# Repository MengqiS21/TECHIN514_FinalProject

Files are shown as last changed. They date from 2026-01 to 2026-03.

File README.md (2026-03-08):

# Pet Activity & Proximity Tracker

A wearable sensing tag for pets and a tabletop display that visualizes daily activity and proximity-based companionship.  
The system is designed as a calm, ambient tool that supports reflection rather than real-time alerts, helping pet owners understand patterns of activity and togetherness over the course of a day. By translating sensed data into a physical gauge, the project emphasizes presence and routine over precise tracking or notifications.

## 1. Overview

### What it does
This project consists of a lightweight sensing device attached to a pet’s collar and a tabletop display device placed in the home. The system tracks the pet’s activity level and estimates proximity to the owner throughout the day, visualizing overall “bond time” using a physical gauge instead of a screen.

### General system sketch
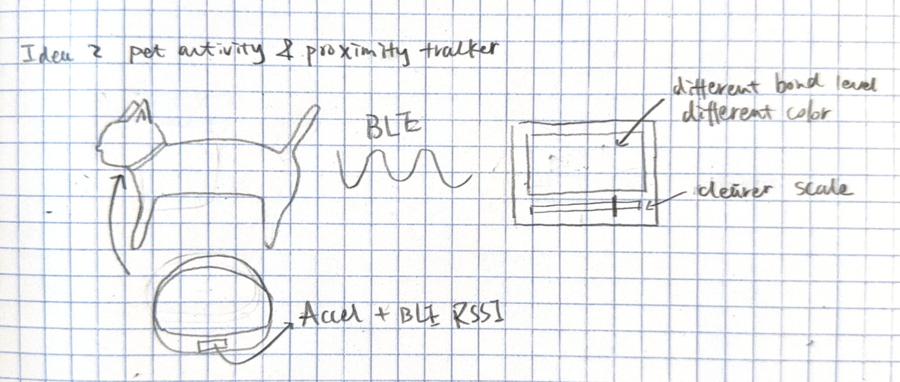
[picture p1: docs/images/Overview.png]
Overall system sketch


### Repository structure
```text
TECHIN514_FinalProject/
├─ README.md
├─ archive/
│  └─ root_pio_legacy/          # early PlatformIO prototype
├─ docs/
│  ├─ images/                   # system diagrams and renders
│  ├─ datasheets/               # component datasheets
│  └─ gantt.xlsx
├─ firmware/
│  ├─ sensor_tag/               # collar sensing tag firmware (ESP32-C3)
│  │  ├─ src/
│  │  ├─ include/
│  │  ├─ lib/
│  │  └─ test/
│  └─ display_meter/            # tabletop display firmware (ESP32-C3)
│     ├─ src/
│     ├─ include/
│     ├─ lib/
│     └─ test/
└─ hardware/
   ├─ pcb/
   │  ├─ sensor_tag/            # sensor-tag PCB project files
   │  ├─ display/               # display PCB project files
   │  ├─ legacy_pcb/            # older PCB iteration
   │  └─ PCB Production/        # Gerbers and drill files
   └─ enclosure/                # enclosure CAD/STL/STEP files
```

## 2. Sensing Device (Pet Collar Tag)

### Description
The sensing device is a lightweight tag mounted on a pet’s collar that detects motion and estimates proximity to the owner. It classifies activity levels (resting, walking, high activity) and tracks how much time the pet spends near the display device without using GPS.

### Detailed sensing device sketch
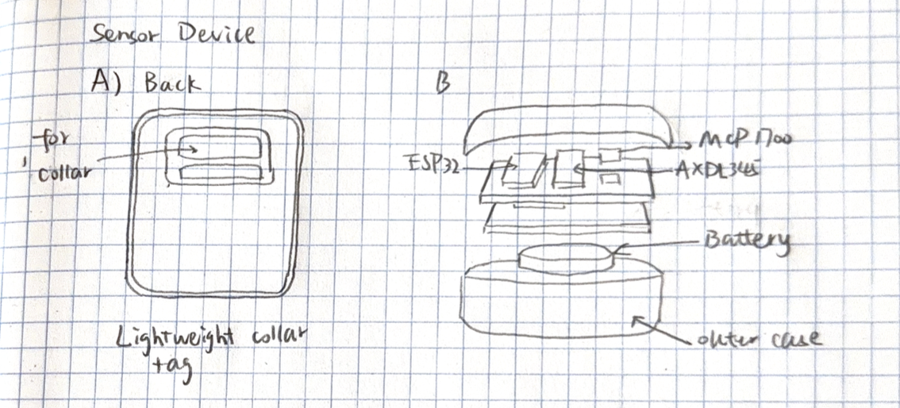
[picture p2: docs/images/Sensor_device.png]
Sensing device sketch


### How it works
- An onboard accelerometer detects motion patterns to estimate activity intensity.
- The sensor samples IMU acceleration for a short time window and computes a compact activity score.
- Summarized data is transmitted periodically to the display device via BLE.

### Signal Processing / Machine Learning (Current Implementation)
- The current system uses **lightweight signal processing**, not a trained machine learning model.
- In `firmware/sensor_tag/src/main.cpp`, the tag samples acceleration for a **1.5 s window** with a **40 ms** sample period.
- For each sample, it computes motion magnitude proxy `|ax| + |ay| + |az|`, averages over the window, and maps it linearly to a **0-100** activity score (`3g -> 100`, clamped).
- This activity score is sent to the display via BLE and mapped to motor/LED behavior.

### Accuracy Numbers (Current Status)
- A labeled dataset evaluation is not yet included in this repository.
- Therefore, formal ML metrics such as **accuracy / precision / recall / F1** are currently **N/A (not reported yet)**.

### Sensors and components (with part numbers)
- **Accelerometer:** ADXL345 (Analog Devices, 3-axis digital accelerometer)
- **Microcontroller + BLE:** ESP32-C3-MINI-1
- **Battery:** CR2032 coin cell *or* 150–300 mAh LiPo battery
- **Power management:** MCP1700 low-dropout regulator
- **Optional proximity aid:** Onboard ESP32 BLE RSSI (no extra sensor required)

## 3. Display Device (Bond Meter)

### Description
The display device is a tabletop “bond meter” that physically visualizes the pet’s daily activity and proximity time using a stepper-motor-driven gauge needle. An LED provides real-time feedback when the pet is nearby, and a button allows users to switch display modes or acknowledge the status.

### Detailed display device sketch
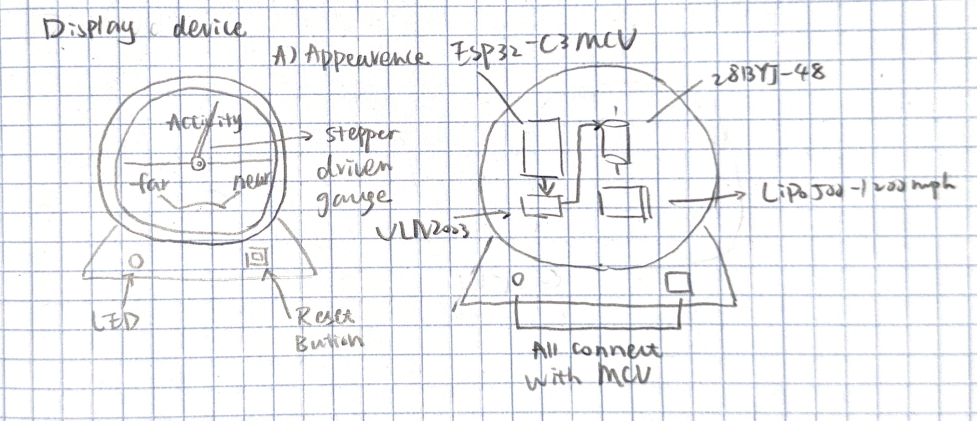
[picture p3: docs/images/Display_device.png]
Display device sketch


### How it works
- The display receives summarized activity and proximity data via BLE.
- The microcontroller maps daily totals to a gauge needle position using a stepper motor.
- The LED indicates current proximity state (e.g., pet nearby vs away).
- The button toggles display modes (activity vs proximity) or resets daily tracking.

### Components (with part numbers)
- **Microcontroller + BLE:** ESP32-C3-MINI-1
- **Stepper motor:** 28BYJ-48 stepper motor
- **Motor driver:** ULN2003 stepper driver
- **LED:** WS2812B single RGB LED *or* standard 5mm LED
- **Button:** Standard tact switch
- **Battery:** 500–1200 mAh LiPo battery

## 4. System Communication & Data Flow

### Wireless communication overview
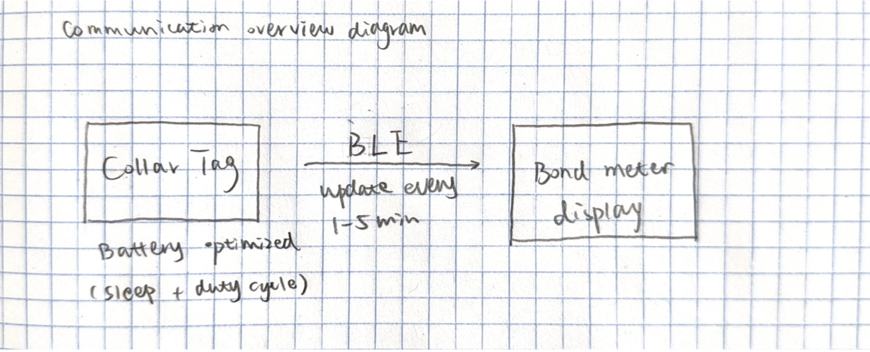
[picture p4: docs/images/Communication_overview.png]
Communication overview diagram


### Detailed system diagram
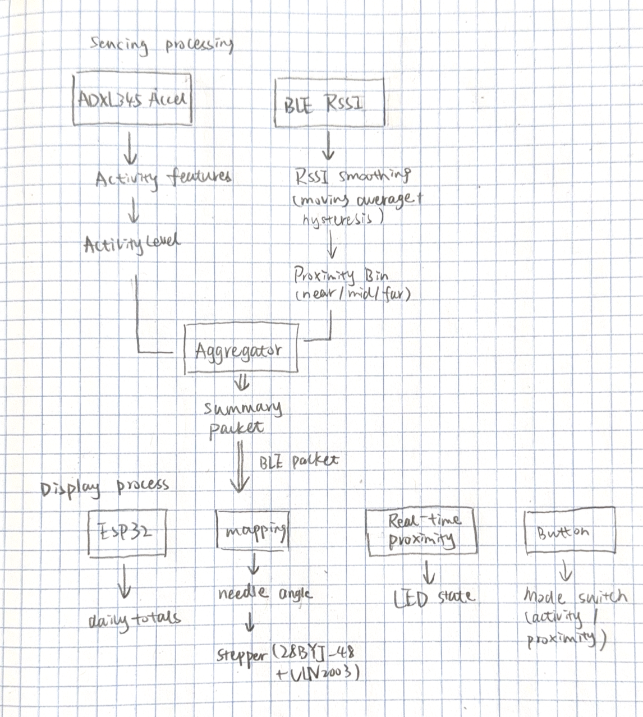
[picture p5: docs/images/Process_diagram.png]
Detailed data flow diagram


## Notes on Power and Feasibility
Both devices are battery-powered and optimized for low-duty-cycle operation. The sensing device minimizes power usage through aggressive sleep scheduling, while the display device uses short stepper motor movements and infrequent updates to maintain reasonable battery life.

### Schematic and PCB Design
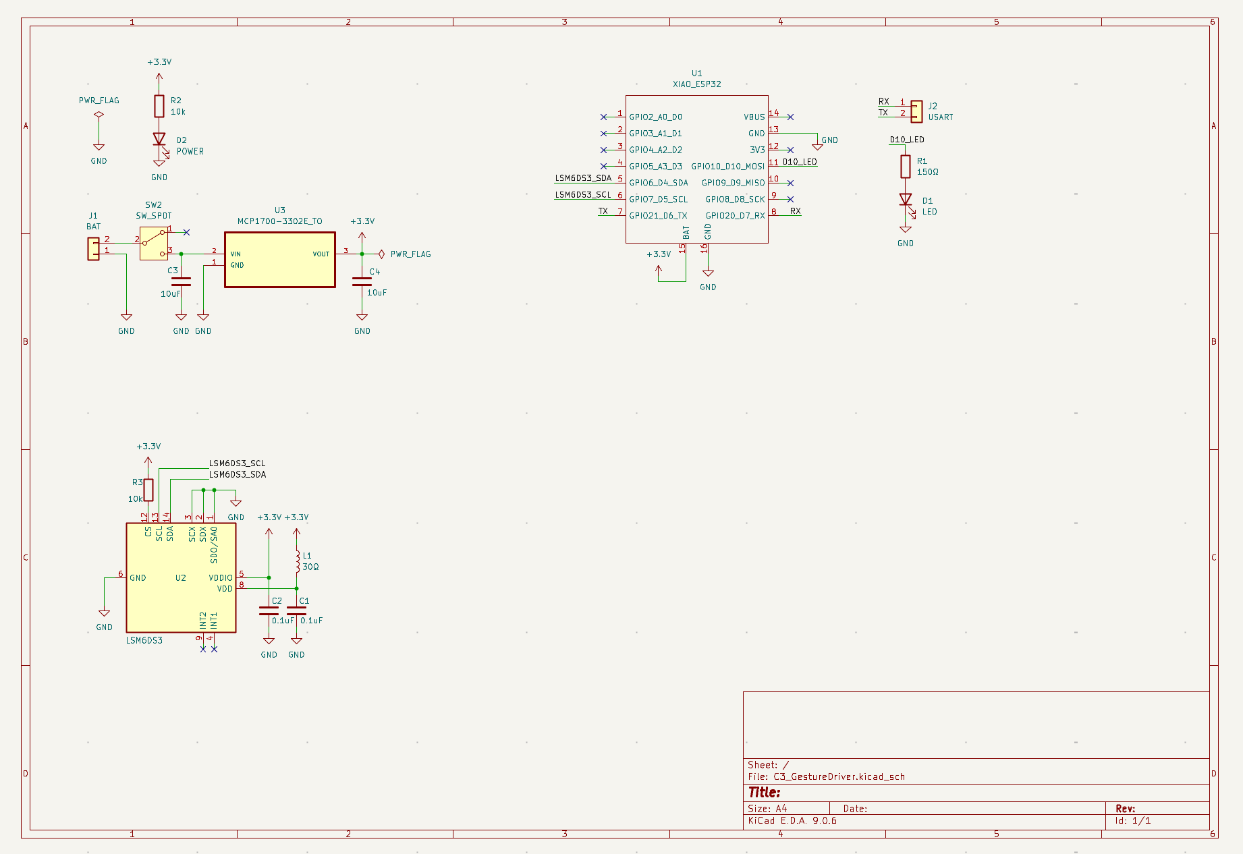
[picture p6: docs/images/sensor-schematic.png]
Detailed Sensor Schematic

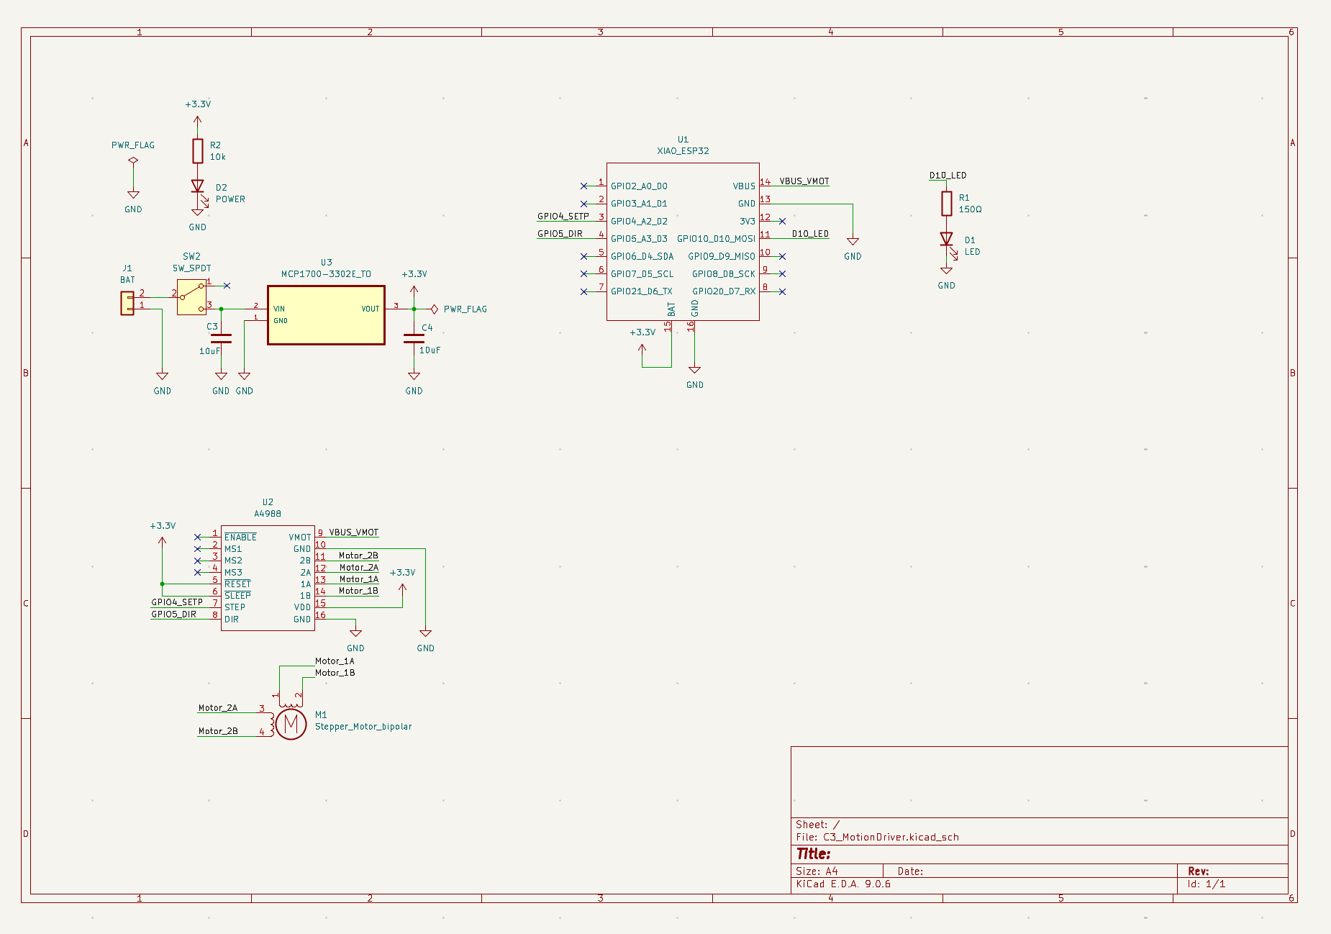
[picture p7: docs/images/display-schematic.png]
Detailed Display Schematic

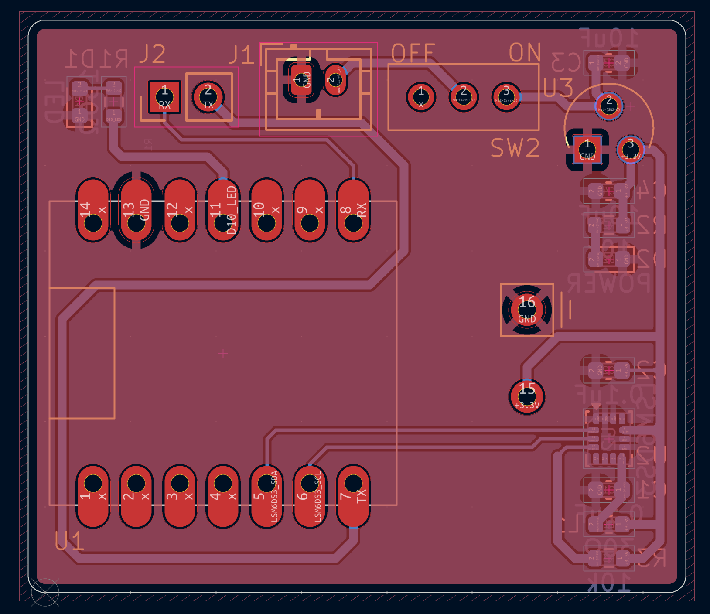
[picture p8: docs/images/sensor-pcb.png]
Detailed PCB


### PCB Production
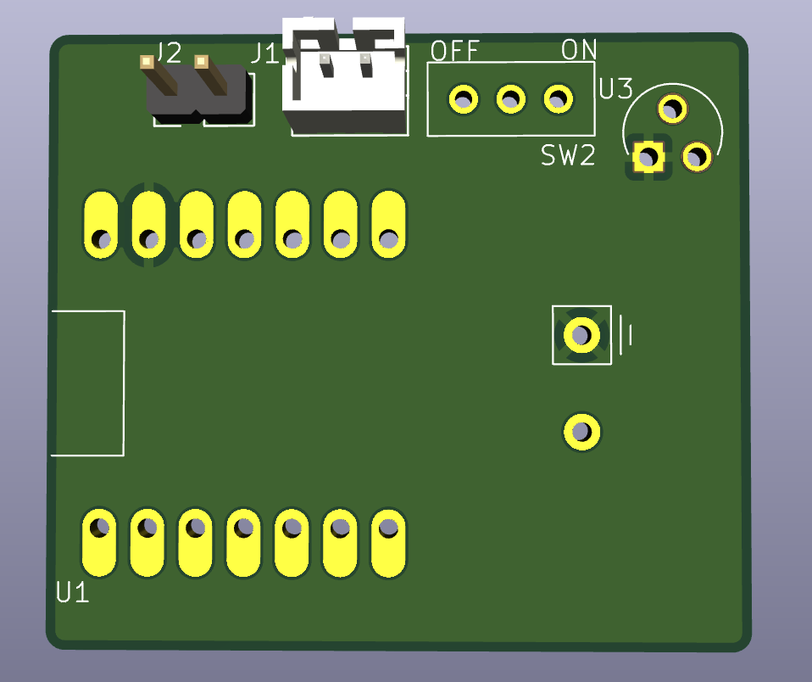
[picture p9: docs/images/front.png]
Detailed 3D View Front PCB

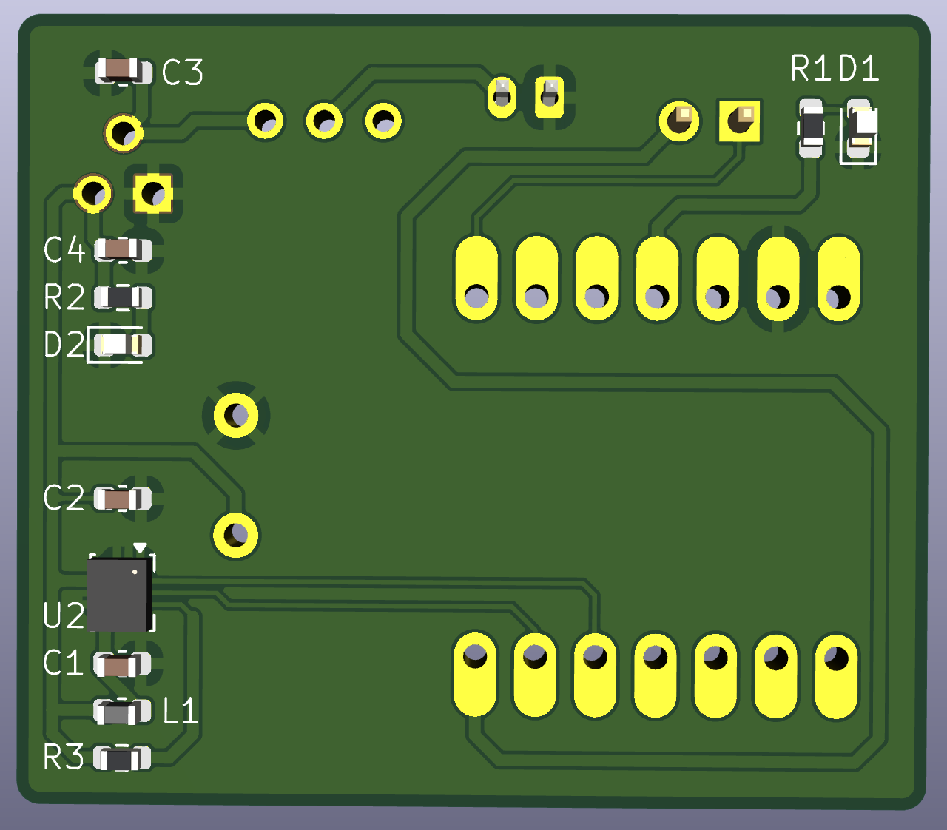
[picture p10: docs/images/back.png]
Detailed 3D View Back PCB


### Battery Life Estimation
https://docs.google.com/spreadsheets/d/1o1SAS0YDETgxqNn3ZR0W69rIJqL8Xmiv9CGHoeJ4H2A/edit?usp=sharing

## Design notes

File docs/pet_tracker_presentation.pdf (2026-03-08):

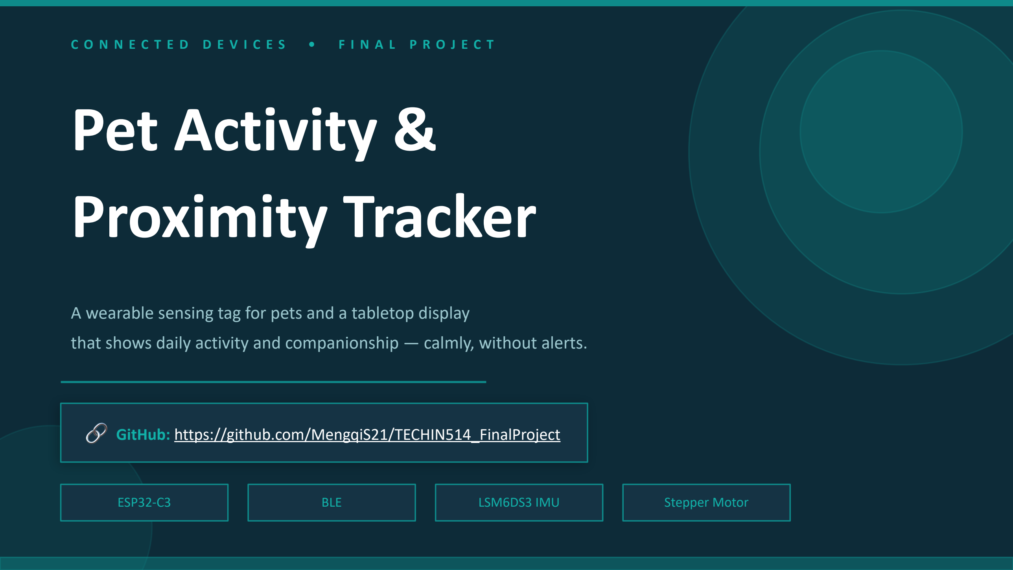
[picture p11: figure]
CONNECTED DEVICES; FINAL PROJECT; Pet Activity & Proximity Tracker; 🔗 GitHub: https://github.com/MengqiS21/TECHIN514_FinalProject; ESP32-C3; BLE; LSM6DS3 IMU; Stepper Motor

### A wearable sensing tag for pets and a tabletop display

that shows daily activity and companionship — calmly, without alerts.

# The Problem

### 😔 You don't know what your pet does all day

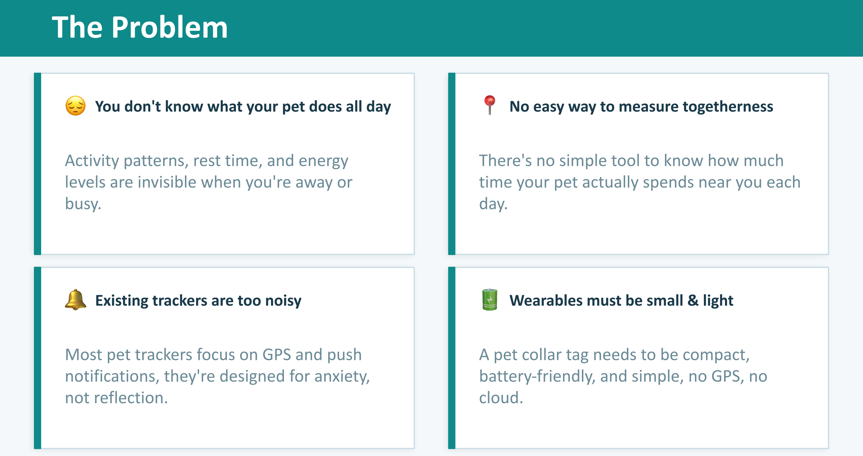
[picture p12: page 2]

## Activity patterns, rest time, and energy levels are invisible when you're away or

busy.

### 📍 No easy way to measure togetherness

## There's no simple tool to know how much time your pet actually spends near you each

day.

### 🔔 Existing trackers are too noisy

## Most pet trackers focus on GPS and push

notifications, they're designed for anxiety, not reflection.

### 🔋 Wearables must be small & light

A pet collar tag needs to be compact,

## battery-friendly, and simple, no GPS, no

cloud.

# Proposed Solution

## 🐾 Collar Sensing Tag

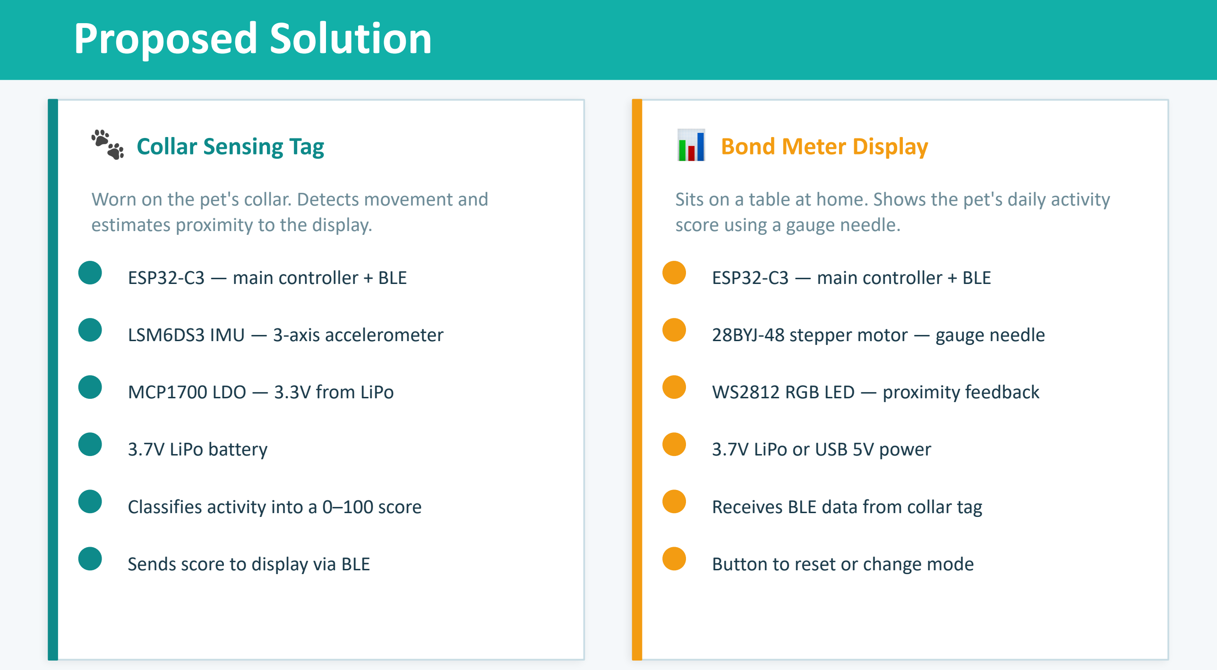
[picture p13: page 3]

Worn on the pet's collar. Detects movement and estimates proximity to the display.

ESP32-C3 — main controller + BLE

LSM6DS3 IMU — 3-axis accelerometer

MCP1700 LDO — 3.3V from LiPo

3.7V LiPo battery

Classifies activity into a 0–100 score

Sends score to display via BLE

## 📊 Bond Meter Display

Sits on a table at home. Shows the pet's daily activity score using a gauge needle.

ESP32-C3 — main controller + BLE

28BYJ-48 stepper motor — gauge needle

WS2812 RGB LED — proximity feedback

3.7V LiPo or USB 5V power

Receives BLE data from collar tag

Button to reset or change mode

# System Architecture

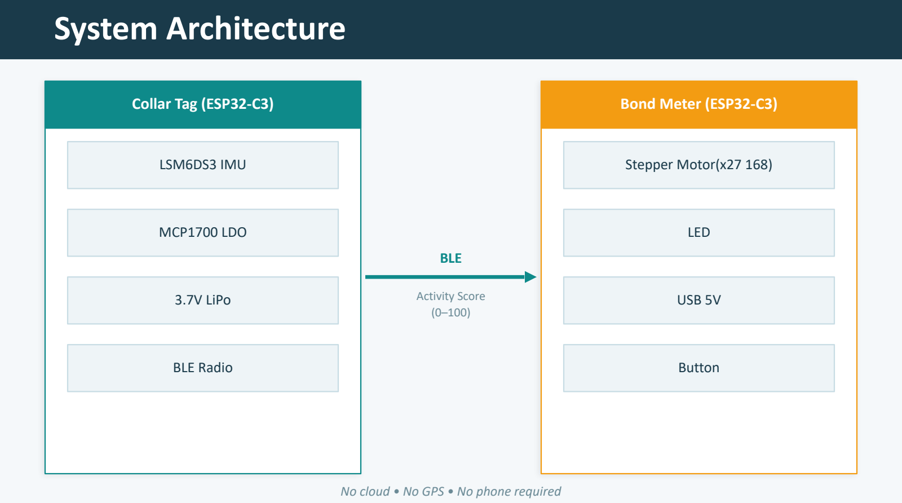
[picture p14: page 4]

### Collar Tag (ESP32-C3)

LSM6DS3 IMU

MCP1700 LDO

3.7V LiPo

BLE Radio

BLE

Activity Score
(0–100)

### Bond Meter (ESP32-C3)

Stepper Motor(x27 168)

LED

USB 5V

Button

No cloud • No GPS • No phone required

# Critical Components & PCB

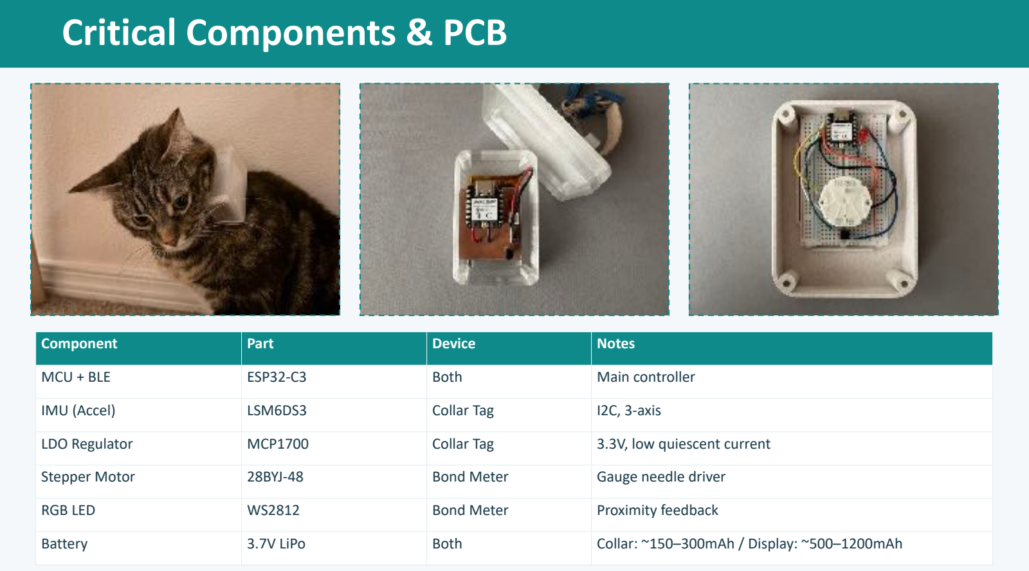
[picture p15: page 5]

Component | Part | Device | Notes
MCU + BLE | ESP32-C3 | Both | Main controller
IMU (Accel) | LSM6DS3 | Collar Tag | I2C, 3-axis
LDO Regulator | MCP1700 | Collar Tag | 3.3V, low quiescent current
Stepper Motor | 28BYJ-48 | Bond Meter | Gauge needle driver
RGB LED | WS2812 | Bond Meter | Proximity feedback
Battery | 3.7V LiPo | Both | Collar: ~150–300mAh / Display: ~500–1200mAh

# Signal Processing

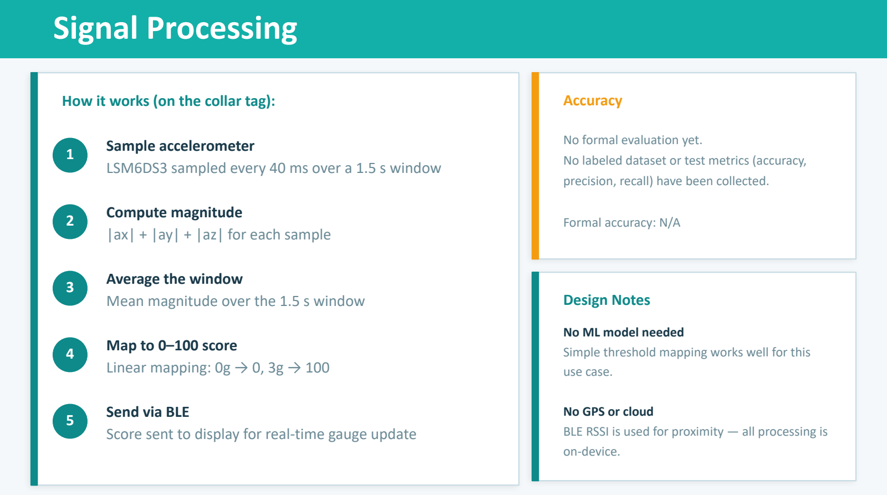
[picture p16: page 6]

### How it works (on the collar tag):

### 1 Sample accelerometer LSM6DS3 sampled every 40 ms over a 1.5 s window

### 2 Compute magnitude |ax| + |ay| + |az| for each sample

### 3 Average the window Mean magnitude over the 1.5 s window

### 4 Map to 0–100 score Linear mapping: 0g → 0, 3g → 100

### 5 Send via BLE Score sent to display for real-time gauge update

### Accuracy

No formal evaluation yet.
No labeled dataset or test metrics (accuracy, precision, recall) have been collected.

Formal accuracy: N/A

### Design Notes

No ML model needed
Simple threshold mapping works well for this use case.

No GPS or cloud
BLE RSSI is used for proximity — all processing is on-device.

# Battery Considerations

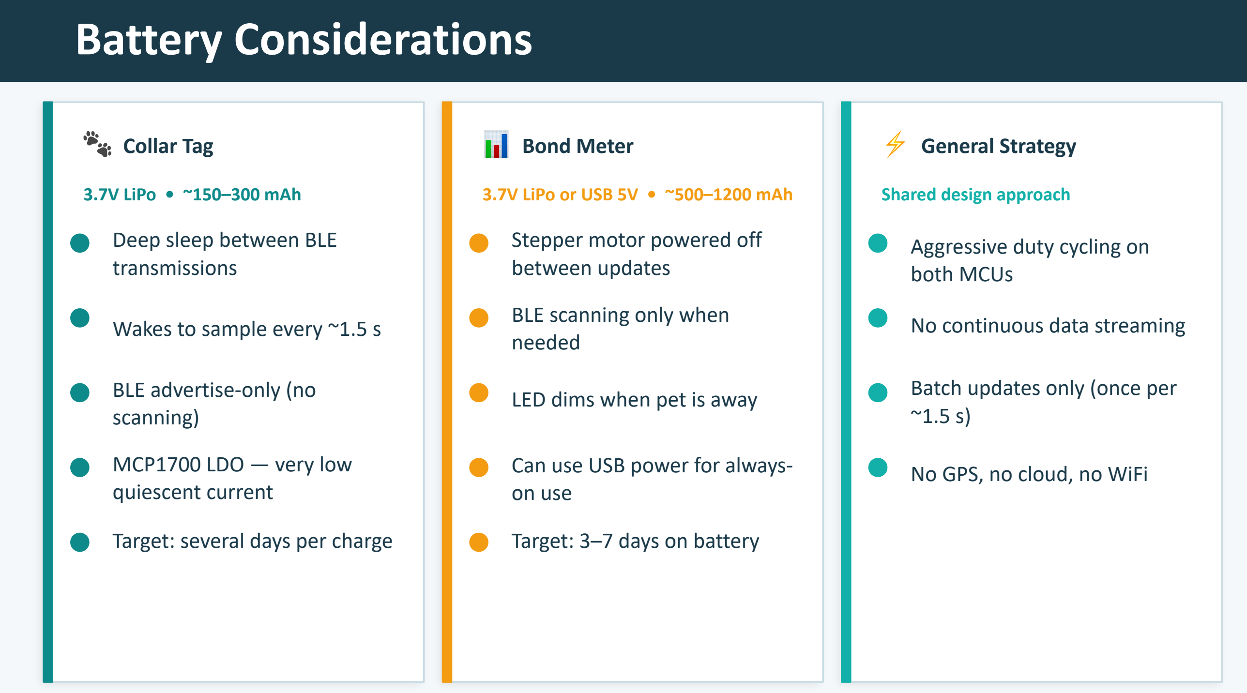
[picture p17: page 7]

### 🐾 Collar Tag

3.7V LiPo • ~150–300 mAh

### Deep sleep between BLE transmissions

### Wakes to sample every ~1.5 s

### BLE advertise-only (no scanning)

### MCP1700 LDO — very low quiescent current

### Target: several days per charge

### 📊 Bond Meter

3.7V LiPo or USB 5V • ~500–1200 mAh

### Stepper motor powered off between updates

### BLE scanning only when needed

### LED dims when pet is away

### Can use USB power for always-on use

### Target: 3–7 days on battery

### ⚡ General Strategy

Shared design approach

### Aggressive duty cycling on both MCUs

### No continuous data streaming

### Batch updates only (once per

~1.5 s)

### No GPS, no cloud, no WiFi

# Budget Summary

Component | Part | Qty | Unit Cost | Total
MCU (ESP32-C3) | Seeed Studio ESP32-C3 XIAO dev module | 2 | ~$10.00 | ~$20.00
IMU | LSM6DS3 module | 1 | ~$7.00 | ~$7.00
LDO Regulator | MCP1700 | 1 | ~$0.95 | ~$0.95
Stepper Motor | X27 168 | 1 | ~$8.00 | ~$8.00
RGB LED | WS2812 | 1 | ~$0.10 | ~$0.10
I2C Pull-up Resistors | 4.7kΩ or 10kΩ ×2 | 1 set | ~$0.10 | ~$0.10
220Ω Resistor | Standard | 1 | <$0.10 | <$0.10
Batteries | LiPo ×2 + connectors | — | ~$8.99 | ~$17.98
PCB Fabrication | JLCPCB / PCBWay (×2 boards) | — | ~$10.00 | ~$10.00
Misc (switch, connectors, enclosure) | — | — | — | ~$8.00
TOTAL ESTIMATED | | | | ~$72.23

* All costs estimated. Final BOM depends on supplier and order quantity.

# Future Work

## 🤖 Collect labeled data & evaluate accuracy

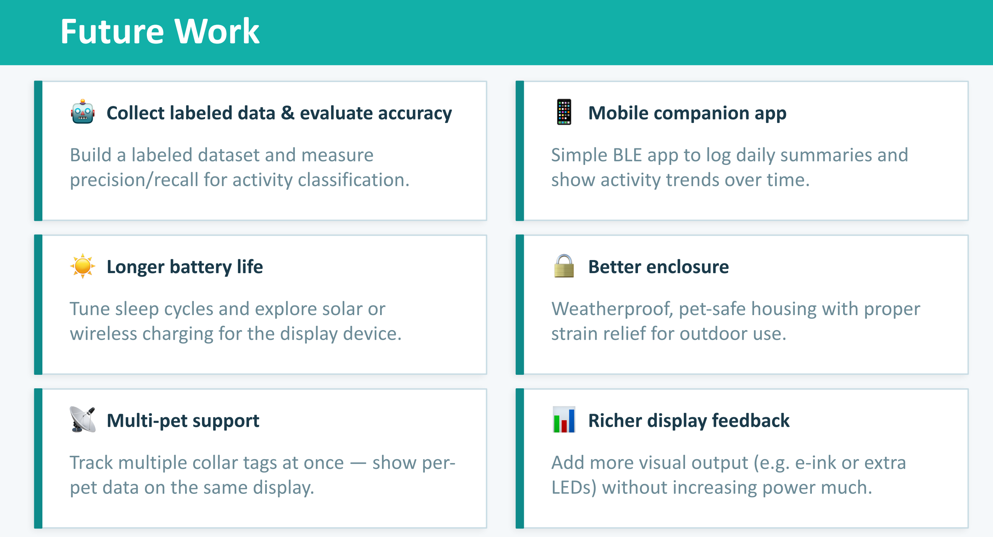
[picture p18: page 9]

## Build a labeled dataset and measure

precision/recall for activity classification.

## 📱 Mobile companion app

## Simple BLE app to log daily summaries and

show activity trends over time.

## ☀ Longer battery life

## Tune sleep cycles and explore solar or

wireless charging for the display device.

## 🔒 Better enclosure

## Weatherproof, pet-safe housing with proper

strain relief for outdoor use.

## 📡 Multi-pet support

## Track multiple collar tags at once — show per-

pet data on the same display.

## 📊 Richer display feedback

## Add more visual output (e.g. e-ink or extra

LEDs) without increasing power much.

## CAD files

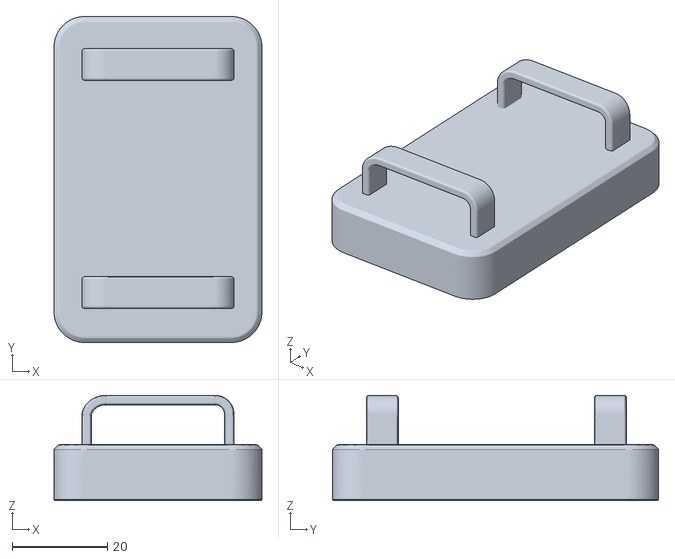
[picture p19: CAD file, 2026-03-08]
hardware/enclosure/sensor-enclosure-top.stl
43.7 x 68.5 x 22.1

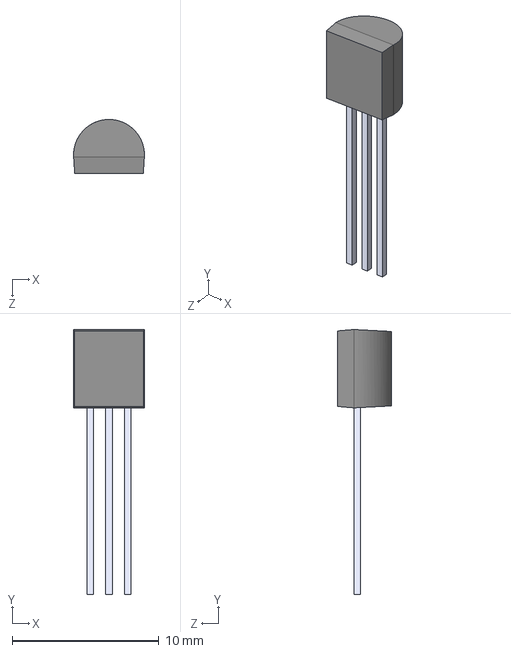
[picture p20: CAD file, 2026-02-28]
hardware/pcb/sensor_tag/MCP1700-3302E_TO/MCP1700-3302E_TO.step
4.82 x 18.0 x 3.68 mm

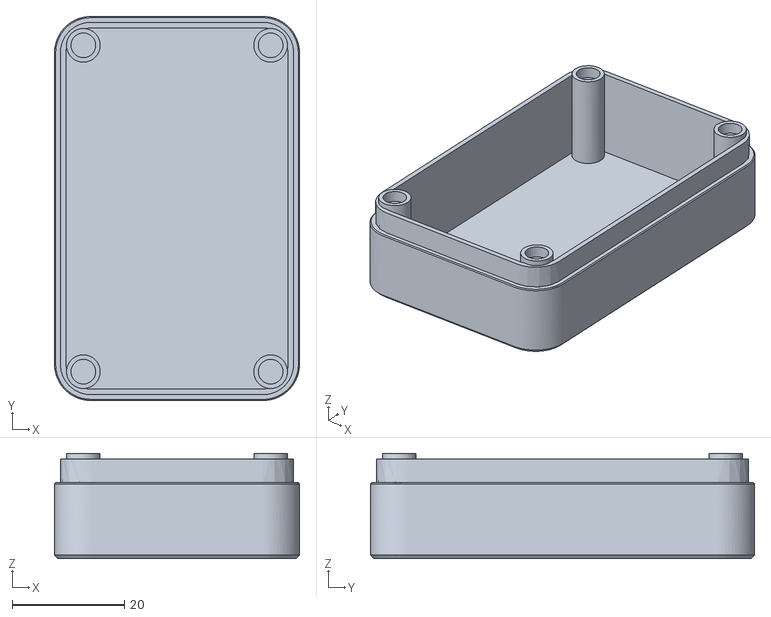
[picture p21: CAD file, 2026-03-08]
hardware/enclosure/sensor-enclosure-base.stl
43.7 x 68.5 x 18.8

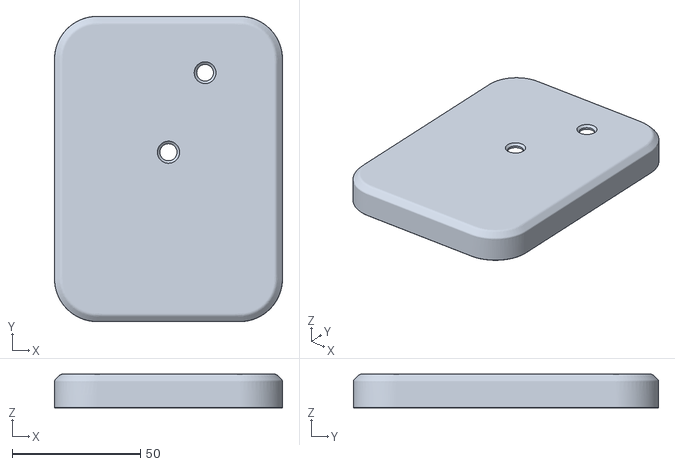
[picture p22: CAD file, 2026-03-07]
hardware/enclosure/display enclosure top.stl
88.8 x 118.9 x 13.2

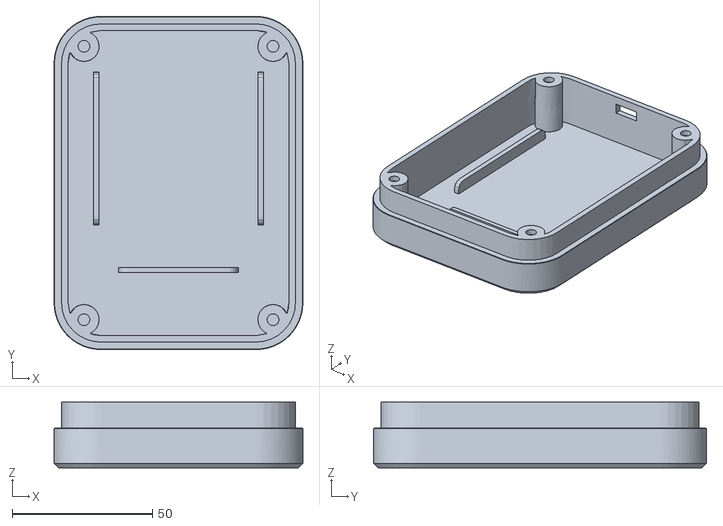
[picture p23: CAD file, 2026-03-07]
hardware/enclosure/display enclosure base.stl
88.8 x 118.9 x 23.5

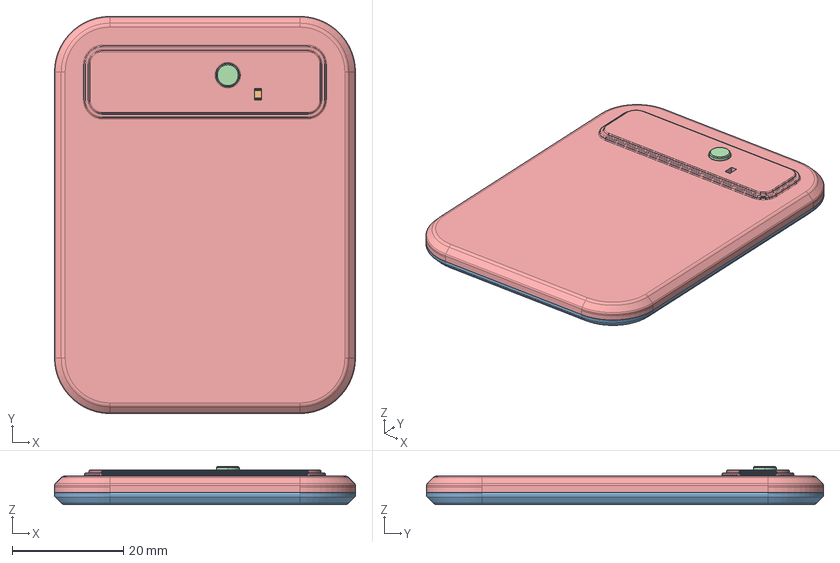
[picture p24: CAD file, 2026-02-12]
hardware/enclosure/PCB enclosure.stp
54.1 x 71.4 x 6.90 mm

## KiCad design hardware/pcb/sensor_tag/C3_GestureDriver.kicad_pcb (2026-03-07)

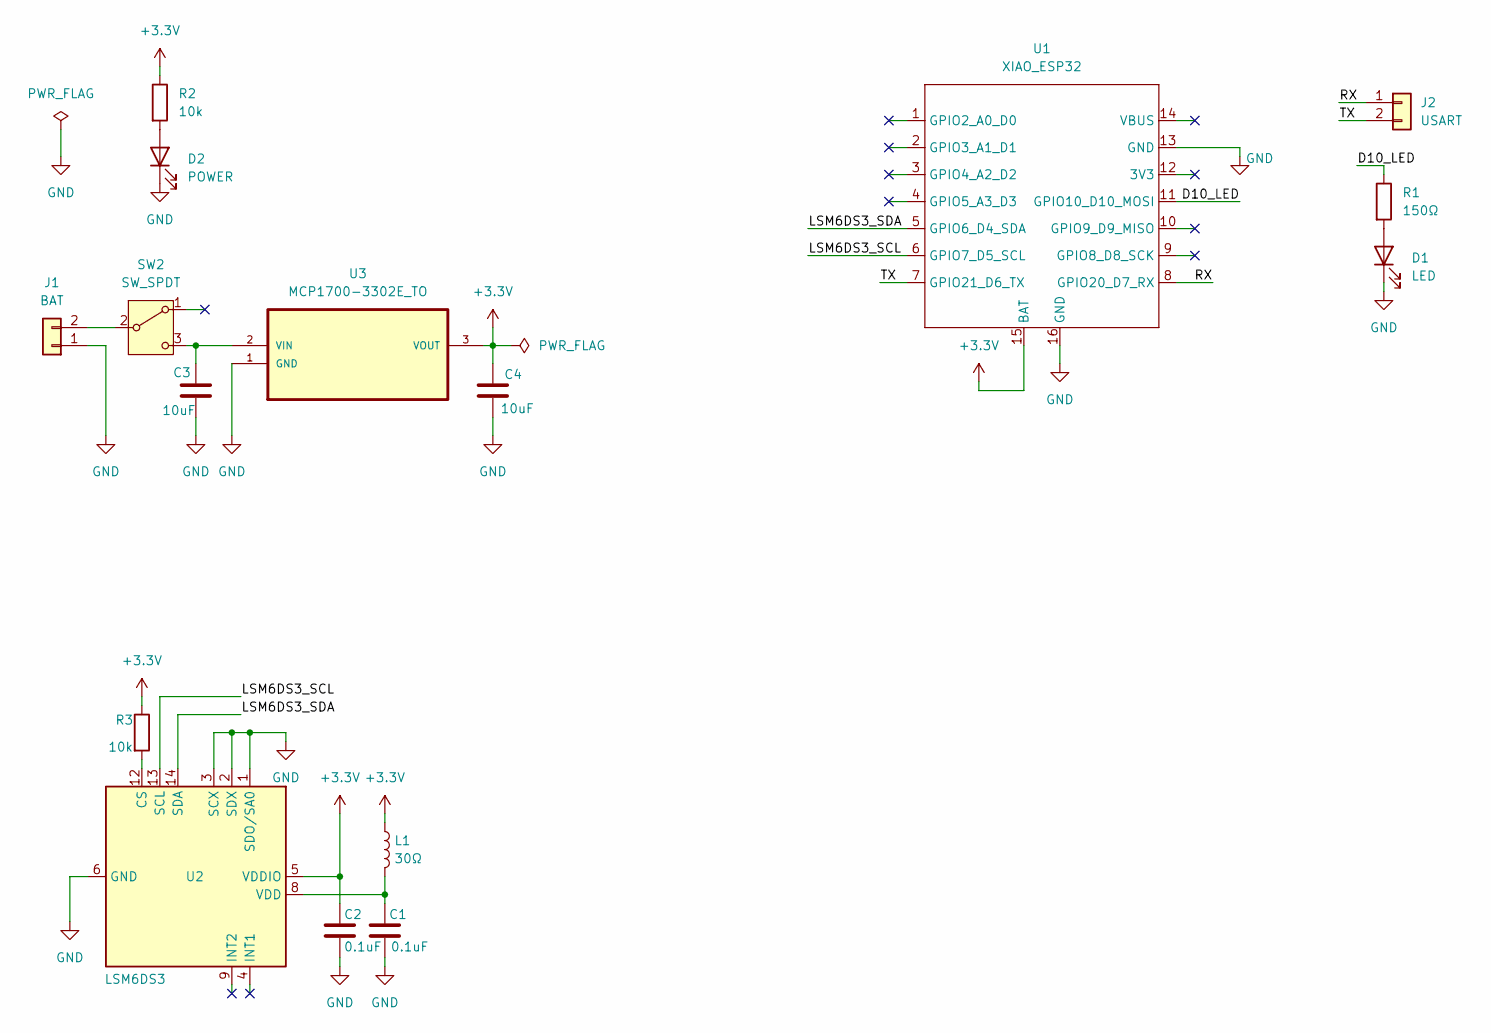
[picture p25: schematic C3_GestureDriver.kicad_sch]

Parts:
C1, C2: 0.1uF; C_0603_1608Metric
C3, C4: 10uF; C_0603_1608Metric
D1: LED; LED_0603_1608Metric
D2: POWER; LED_0603_1608Metric
J1: BAT; JST_PH_B2B-PH-K_1x02_P2.00mm_Vertical
J2: USART; PinHeader_1x02_P2.54mm_Vertical
L1: 30Ω; L_0603_1608Metric
R1: 150Ω; R_0603_1608Metric
R2, R3: 10k; R_0603_1608Metric
SW2: SW_SPDT; SS-12D00-Gx
U1: XIAO_ESP32
U2: LSM6DS3; LGA-14_3x2.5mm_P0.5mm_LayoutBorder3x4y
U3: MCP1700-3302E_TO; TO127P254X495-3; MPN MCP1700-3302E/TO

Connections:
+3.3V: C2.1, C4.1, L1.1, R2.1, R3.1, U1.15 (BAT), U2.5 (VDDIO), U3.3 (VOUT)
/D10_LED: R1.1, U1.11 (GPIO10_D10_MOSI)
/LSM6DS3_SCL: U1.6 (GPIO7_D5_SCL), U2.13 (SCL)
/LSM6DS3_SDA: U1.5 (GPIO6_D4_SDA), U2.14 (SDA)
/RX: J2.1, U1.8 (GPIO20_D7_RX)
/TX: J2.2, U1.7 (GPIO21_D6_TX)
GND: C1.2, C2.2, C3.2, C4.2, D1.1 (K), D2.1 (K), J1.1, U1.13 (GND), U1.16 (GND), U2.1 (SDO/SA0), U2.2 (SDX), U2.3 (SCX), U2.6 (GND), U2.7 (GND), U3.1 (GND)
unnamed: D1.2 (A), R1.2
unnamed: D2.2 (A), R2.2
unnamed: J1.2, SW2.2 (B)
unnamed: C3.1, SW2.3 (C), U3.2 (VIN)
unnamed: R3.2, U2.12 (CS)
unnamed: C1.1, L1.2, U2.8 (VDD)

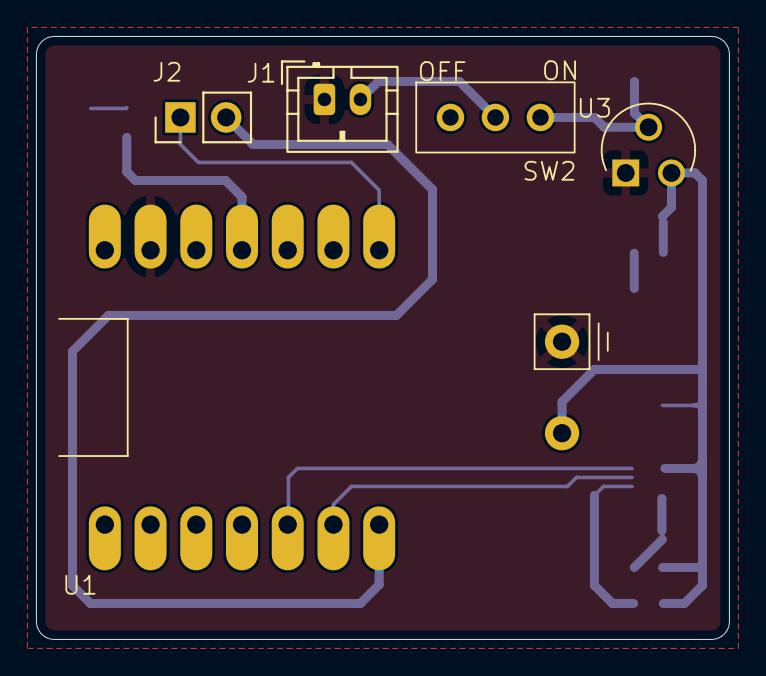
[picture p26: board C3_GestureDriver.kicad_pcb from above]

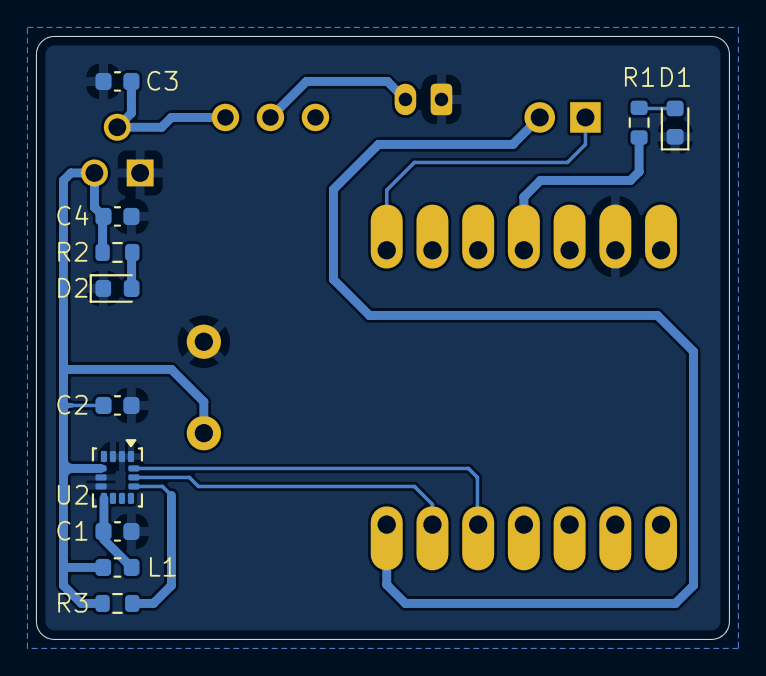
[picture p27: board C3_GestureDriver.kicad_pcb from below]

Board: 2 copper layers, 38.5 x 33.5 mm, 16 parts (11 on the bottom side), 13 nets.

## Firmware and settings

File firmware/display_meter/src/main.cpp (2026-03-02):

#include <Arduino.h>
#include <BLEDevice.h>
#include <cstring>

#include "ble_protocol.h"
#include "config.h"
#include "led_status.h"
#include "motor_gauge.h"
#include "pins.h"
#include "power_stages.h"

enum class DisplayState {
  BOOT,
  BLE_SCAN_CONNECT,
  WAIT_FOR_DATA,
  UPDATE_DISPLAY,
  IDLE,
};

namespace {

class DisplayClientCallbacks : public BLEClientCallbacks {
 public:
  void onConnect(BLEClient* /*client*/) override {}

  void onDisconnect(BLEClient* /*client*/) override {
    Serial.println("BLE disconnected.");
    connected_ = false;
  }

  bool connected() const { return connected_; }
  void setConnected(bool value) { connected_ = value; }

 private:
  bool connected_ = false;
};

DisplayState g_state = DisplayState::BOOT;
DisplayClientCallbacks g_client_callbacks;
BLEClient* g_client = nullptr;
BLERemoteCharacteristic* g_remote_char = nullptr;

ActivityPayload g_last_payload{};
volatile bool g_payload_ready = false;
uint32_t g_wait_start_ms = 0;

bool g_motor_ready = false;
bool g_ble_initialized = false;

void notifyCallback(BLERemoteCharacteristic* /*remote*/, uint8_t* data, size_t len, bool /*isNotify*/) {
  if (len < sizeof(ActivityPayload)) {
    return;
  }
  memcpy(&g_last_payload, data, sizeof(ActivityPayload));
  g_payload_ready = true;
}

bool validatePins() {
  bool ok = true;
  if (PIN_MOTOR_IN1 < 0) {
    Serial.println("ERROR: PIN_MOTOR_IN1 not set. Edit include/pins.h");
    ok = false;
  }
  if (PIN_MOTOR_IN2 < 0) {
    Serial.println("ERROR: PIN_MOTOR_IN2 not set. Edit include/pins.h");
    ok = false;
  }
  if (PIN_MOTOR_IN3 < 0) {
    Serial.println("ERROR: PIN_MOTOR_IN3 not set. Edit include/pins.h");
    ok = false;
  }
  if (PIN_MOTOR_IN4 < 0) {
    Serial.println("ERROR: PIN_MOTOR_IN4 not set. Edit include/pins.h");
    ok = false;
  }
  return ok;
}

bool ensureBleInit() {
  if (g_ble_initialized) {
    return true;
  }
  BLEDevice::init(kBleDeviceName);
  g_ble_initialized = true;
  return true;
}

bool connectToSensor() {
  if (!ensureBleInit()) {
    return false;
  }

  BLEScan* scan = BLEDevice::getScan();
  scan->setActiveScan(true);
  BLEScanResults results = scan->start(kBleScanSeconds, false);

  BLEAdvertisedDevice* target = nullptr;
  for (int i = 0; i < results.getCount(); ++i) {
    BLEAdvertisedDevice device = results.getDevice(i);
    if (device.haveServiceUUID() && device.isAdvertisingService(BLEUUID(BLE_SERVICE_UUID))) {
      target = new BLEAdvertisedDevice(device);
      break;
    }
  }

  scan->clearResults();

  if (target == nullptr) {
    Serial.println("BLE scan: target service not found.");
    return false;
  }

  if (g_client == nullptr) {
    g_client = BLEDevice::createClient();
    g_client->setClientCallbacks(&g_client_callbacks);
  }

  if (!g_client->connect(target)) {
    Serial.println("BLE connect failed.");
    delete target;
    return false;
  }
  delete target;
  delay(500);  // Allow GATT attribute discovery to complete

  BLERemoteService* service = g_client->getService(BLEUUID(BLE_SERVICE_UUID));
  if (service == nullptr) {
    Serial.println("BLE service missing on peer.");
    g_client->disconnect();
    return false;
  }

  g_remote_char = service->getCharacteristic(BLEUUID(BLE_CHAR_UUID));
  if (g_remote_char == nullptr) {
    Serial.println("BLE characteristic missing on peer.");
    g_client->disconnect();
    return false;
  }

  if (!g_remote_char->canNotify()) {
    Serial.println("BLE characteristic does not support notify.");
    g_client->disconnect();
    return false;
  }

  BLERemoteDescriptor* cccd =
      g_remote_char->getDescriptor(BLEUUID((uint16_t)0x2902));
  if (cccd == nullptr) {
    Serial.println("BLE CCCD descriptor not found on peer.");
    g_client->disconnect();
    return false;
  }

  if (!g_remote_char->registerForNotify(notifyCallback)) {
    Serial.println("BLE notify subscription failed.");
    g_client->disconnect();
    return false;
  }

  g_client_callbacks.setConnected(true);
  g_wait_start_ms = millis();
  return true;
}

bool isBleConnected() {
  if (g_client == nullptr) {
    return false;
  }
  return g_client->isConnected() && g_client_callbacks.connected();
}

void updateDisplayFromPayload() {
  const uint16_t activity = (g_last_payload.activity > 100) ? 100 : g_last_payload.activity;

  Serial.print("RX seq=");
  Serial.print(g_last_payload.seq);
  Serial.print(" activity=");
  Serial.print(activity);
  Serial.print(" battery_mv=");
  Serial.println(g_last_payload.battery_mv);

  if (g_motor_ready) {
    motor_gauge::setTargetFromActivity(activity);
  } else {
    Serial.println("Motor pins not configured; display update is print-only.");
  }
  led_status::setFromActivity(activity);
}

}  // namespace

void setup() {
  Serial.begin(115200);
  delay(300);
}

void loop() {
  switch (g_state) {
    case DisplayState::BOOT:
      validatePins();
      g_motor_ready = motor_gauge::init();
      led_status::init();
      g_state = DisplayState::BLE_SCAN_CONNECT;
      break;

    case DisplayState::BLE_SCAN_CONNECT:
      LOG_STAGE("BLE_SCAN");
      if (connectToSensor()) {
        LOG_STAGE("BLE_CONNECTED");
        g_state = DisplayState::WAIT_FOR_DATA;
      } else {
        delay(400);
      }
      break;

    case DisplayState::WAIT_FOR_DATA:
      if (!isBleConnected()) {
        g_state = DisplayState::BLE_SCAN_CONNECT;
        break;
      }

      if (g_payload_ready) {
        g_state = DisplayState::UPDATE_DISPLAY;
        break;
      }

      if (millis() - g_wait_start_ms > kDataWaitTimeoutMs) {
        g_state = DisplayState::IDLE;
      }
      delay(20);
      break;

    case DisplayState::UPDATE_DISPLAY:
      LOG_STAGE("DISPLAY_UPDATE");
      updateDisplayFromPayload();
      g_payload_ready = false;
      g_wait_start_ms = millis();
      g_state = DisplayState::WAIT_FOR_DATA;
      break;

    case DisplayState::IDLE:
      LOG_STAGE("IDLE");
      delay(kIdleDelayMs);
      if (!isBleConnected()) {
        g_state = DisplayState::BLE_SCAN_CONNECT;
      } else {
        g_wait_start_ms = millis();
        g_state = DisplayState::WAIT_FOR_DATA;
      }
      break;
  }
}

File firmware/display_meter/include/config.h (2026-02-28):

#ifndef DISPLAY_CONFIG_H
#define DISPLAY_CONFIG_H

#include <stdint.h>

static constexpr const char* kBleDeviceName = "TECHIN514_DISPLAY";
static constexpr const char* kBleServiceUuid = "6f7f0001-8f3b-4c3a-a39a-3f8ec4dca101";
static constexpr const char* kBleCharUuid = "6f7f0002-8f3b-4c3a-a39a-3f8ec4dca101";

static constexpr uint32_t kBleScanSeconds = 4;
static constexpr uint32_t kDataWaitTimeoutMs = 8000;
static constexpr uint32_t kIdleDelayMs = 300;

static constexpr int kGaugeMaxSteps = 600;
static constexpr uint32_t kMotorStepDelayUs = 1200;

#endif

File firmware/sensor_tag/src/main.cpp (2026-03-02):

#include <Arduino.h>
#include <BLEDevice.h>
#include <esp_sleep.h>
#include <math.h>

#include "activity_algo.h"
#include "ble_protocol.h"
#include "config.h"
#include "imu_lsm6ds3.h"
#include "pins.h"
#include "power_stages.h"

enum class SensorState {
  BOOT,
  IMU_INIT,
  SENSE_IMU,
  PROCESS,
  BLE_TX,
  RADIO_OFF,
  DEEP_SLEEP,
};

namespace {

class SensorServerCallbacks : public BLEServerCallbacks {
 public:
  void onConnect(BLEServer* /*server*/) override { connected_ = true; }
  void onDisconnect(BLEServer* server) override {
    connected_ = false;
    server->startAdvertising();
  }

  bool isConnected() const { return connected_; }

 private:
  bool connected_ = false;
};

SensorState g_state = SensorState::BOOT;
imu::Lsm6ds3 g_imu;
bool g_has_i2c_pins = false;
bool g_imu_ready = false;
uint32_t g_seq = 0;
uint16_t g_activity = 0;
uint16_t g_battery_mv = 0;

float g_sum_abs_accel = 0.0f;
uint32_t g_sample_count = 0;

bool validateRequiredPins() {
  bool ok = true;
  if (PIN_I2C_SDA < 0) {
    Serial.println("ERROR: PIN_I2C_SDA not set. Edit include/pins.h");
    ok = false;
  }
  if (PIN_I2C_SCL < 0) {
    Serial.println("ERROR: PIN_I2C_SCL not set. Edit include/pins.h");
    ok = false;
  }
  return ok;
}

uint16_t readBatteryMv() {
  if (PIN_BATTERY_ADC < 0) {
    return 0;
  }
  const int raw = analogRead(PIN_BATTERY_ADC);
  // Minimal placeholder conversion for 12-bit ADC @ 3.3V.
  const uint32_t mv = static_cast<uint32_t>(raw) * 3300UL / 4095UL;
  return static_cast<uint16_t>(mv);
}

void sampleImuWindow() {
  LOG_STAGE("IMU_SAMPLING_START");
  g_sum_abs_accel = 0.0f;
  g_sample_count = 0;

  if (!g_imu_ready) {
    Serial.println("IMU not ready; skipping sampling.");
    return;
  }

  const uint32_t start_ms = millis();
  while (millis() - start_ms < kImuSampleWindowMs) {
    imu::Sample s = {0.0f, 0.0f, 0.0f};
    if (g_imu.readAccel(s)) {
      g_sum_abs_accel += fabsf(s.ax_g) + fabsf(s.ay_g) + fabsf(s.az_g);
      ++g_sample_count;
    }
    delay(kImuSamplePeriodMs);
  }

  Serial.print("IMU samples: ");
  Serial.println(g_sample_count);
}

void sendBlePayload() {
  LOG_STAGE("BLE_ON");

  BLEDevice::init(kBleDeviceName);
  BLEServer* server = BLEDevice::createServer();
  auto* callbacks = new SensorServerCallbacks();
  server->setCallbacks(callbacks);

  BLEService* service = server->createService(BLEUUID(BLE_SERVICE_UUID));
  BLECharacteristic* ch = service->createCharacteristic(
      BLEUUID(BLE_CHAR_UUID),
      BLECharacteristic::PROPERTY_READ | BLECharacteristic::PROPERTY_NOTIFY);

  service->start();

  BLEAdvertising* adv = BLEDevice::getAdvertising();
  adv->addServiceUUID(BLEUUID(BLE_SERVICE_UUID));
  adv->start();

  const uint32_t start_wait = millis();
  while (!callbacks->isConnected() && (millis() - start_wait < kBleConnectTimeoutMs)) {
    delay(20);
  }

  if (callbacks->isConnected()) {
    ActivityPayload payload{};
    payload.seq = g_seq;
    payload.activity = g_activity;
    payload.battery_mv = g_battery_mv;

    LOG_STAGE("BLE_SEND");
    ch->setValue(reinterpret_cast<uint8_t*>(&payload), sizeof(payload));
    ch->notify();
    delay(kBlePostNotifyDelayMs);
  } else {
    Serial.println("BLE: no central connected before timeout.");
  }

  adv->stop();
  LOG_STAGE("BLE_OFF");
  BLEDevice::deinit(true);
}

void enterDeepSleep() {
  LOG_STAGE("DEEP_SLEEP");
  esp_sleep_enable_timer_wakeup(static_cast<uint64_t>(kDeepSleepSeconds) * 1000000ULL);
  Serial.flush();
  delay(50);
  esp_deep_sleep_start();
}

}  // namespace

void setup() {
  Serial.begin(115200);
  delay(300);
}

void loop() {
  switch (g_state) {
    case SensorState::BOOT:
      LOG_STAGE("IDLE");
      g_has_i2c_pins = validateRequiredPins();
      g_state = SensorState::IMU_INIT;
      break;

    case SensorState::IMU_INIT: {
      g_imu_ready = false;
      if (!g_has_i2c_pins) {
        Serial.println("I2C pins missing; IMU init skipped.");
        g_state = SensorState::SENSE_IMU;
        break;
      }

      for (uint8_t i = 0; i < kImuInitRetries; ++i) {
        if (g_imu.begin()) {
          g_imu_ready = true;
          break;
        }
        Serial.print("IMU init failed, retry ");
        Serial.println(i + 1);
        delay(100);
      }

      if (!g_imu_ready) {
        Serial.println("IMU init failed after retries; using activity=0.");
      }
      g_state = SensorState::SENSE_IMU;
      break;
    }

    case SensorState::SENSE_IMU:
      sampleImuWindow();
      g_state = SensorState::PROCESS;
      break;

    case SensorState::PROCESS: {
      if (g_sample_count > 0) {
        const float avg = g_sum_abs_accel / static_cast<float>(g_sample_count);
        g_activity = activity::computeActivityFromAverage(avg);
      } else {
        g_activity = 0;
      }
      g_battery_mv = readBatteryMv();
      Serial.print("Activity: ");
      Serial.println(g_activity);
      g_state = SensorState::BLE_TX;
      break;
    }

    case SensorState::BLE_TX:
      sendBlePayload();
      g_state = SensorState::RADIO_OFF;
      break;

    case SensorState::RADIO_OFF:
      ++g_seq;
      g_state = SensorState::DEEP_SLEEP;
      break;

    case SensorState::DEEP_SLEEP:
      enterDeepSleep();
      break;
  }
}

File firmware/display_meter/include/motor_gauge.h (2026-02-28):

#ifndef DISPLAY_MOTOR_GAUGE_H
#define DISPLAY_MOTOR_GAUGE_H

#include <Arduino.h>

#include "config.h"
#include "pins.h"

namespace motor_gauge {

namespace {
constexpr int kPins[4] = {PIN_MOTOR_IN1, PIN_MOTOR_IN2, PIN_MOTOR_IN3, PIN_MOTOR_IN4};
constexpr uint8_t kHalfStepSeq[8][4] = {
    {1, 0, 0, 0},
    {1, 1, 0, 0},
    {0, 1, 0, 0},
    {0, 1, 1, 0},
    {0, 0, 1, 0},
    {0, 0, 1, 1},
    {0, 0, 0, 1},
    {1, 0, 0, 1},
};
}  // namespace

inline bool& motorReady() {
  static bool ready = false;
  return ready;
}

inline int& currentStep() {
  static int step = 0;
  return step;
}

inline int& currentPos() {
  static int pos = 0;
  return pos;
}

inline bool init() {
  for (int i = 0; i < 4; ++i) {
    if (kPins[i] < 0) {
      return false;
    }
  }

  for (int i = 0; i < 4; ++i) {
    pinMode(kPins[i], OUTPUT);
    digitalWrite(kPins[i], LOW);
  }

  motorReady() = true;
  currentStep() = 0;
  currentPos() = 0;
  return true;
}

inline void applyStep(uint8_t seqIndex) {
  for (int i = 0; i < 4; ++i) {
    digitalWrite(kPins[i], kHalfStepSeq[seqIndex][i]);
  }
}

inline void stepMotor(int dir) {
  if (dir > 0) {
    currentStep() = (currentStep() + 1) & 0x07;
  } else {
    currentStep() = (currentStep() + 7) & 0x07;
  }
  applyStep(static_cast<uint8_t>(currentStep()));
  delayMicroseconds(kMotorStepDelayUs);
}

inline int clampTarget(int raw) {
  if (raw < 0) {
    return 0;
  }
  if (raw > kGaugeMaxSteps) {
    return kGaugeMaxSteps;
  }
  return raw;
}

inline void setTargetFromActivity(uint16_t activity) {
  if (!motorReady()) {
    static bool warned = false;
    if (!warned) {
      Serial.println("WARNING: Motor pins unset or not initialized; skipping motor movement.");
      warned = true;
    }
    return;
  }

  const uint16_t clamped = (activity > 100) ? 100 : activity;
  const int target = clampTarget((clamped * kGaugeMaxSteps) / 100);

  while (currentPos() < target) {
    stepMotor(+1);
    ++currentPos();
  }
  while (currentPos() > target) {
    stepMotor(-1);
    --currentPos();
  }
}

}  // namespace motor_gauge

#endif

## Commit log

2026-01-25 add kicad
    [techin514_final_sensor_pcb.kicad_pcb, techin514_final_sensor_pcb.kicad_sch]
2026-01-25 update BOM
    [techin514_final_BOM.csv]
2026-01-26 update schematic
    [techin514_final_sensor_pcb.kicad_sch]
2026-01-27 update schematic and pcb
    [techin514_final_sensor_pcb.kicad_pcb, techin514_final_sensor_pcb.kicad_sch]
2026-01-28 update pcb
    [techin514_final_sensor_pcb.kicad_pcb, techin514_final_sensor_pcb.kicad_sch]
2026-01-28 update schematic pdf
2026-01-31 updated drl
    [techin514_final_sensor_pcb.kicad_pcb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]
2026-01-31 upload gcb files
    [techin514_final_sensor_pcb-B_Cu.gbr, techin514_final_sensor_pcb-B_Mask.gbr, techin514_final_sensor_pcb-B_Paste.gbr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]
2026-02-02 upload pcb and schematic pictures
2026-02-04 updated schematic and PCB
    [techin514_final_sensor_pcb.kicad_pcb, techin514_final_sensor_pcb.kicad_sch]
2026-02-04 updated PCB
    [techin514_final_sensor_pcb.kicad_pcb, techin514_final_sensor_pcb.kicad_sch]
2026-02-08 update ble
    [techin514_final_sensor_pcb.kicad_pcb]
2026-02-12 PCB enclosure
    [PCB enclosure.stp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]
2026-02-25 update code
    [techin514_final_sensor_pcb-B_Cu.gbr, techin514_final_sensor_pcb-B_Mask.gbr, techin514_final_sensor_pcb-B_Paste.gbr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]
2026-02-28 update structure
    [PCB enclosure.stp]
2026-03-02 update sensor code
2026-03-07 update everything
    [C3_GestureDriver-B_Cu.gbr, C3_GestureDriver-B_Mask.gbr, C3_GestureDriver-B_Paste.gbr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]
2026-03-08 update display pin
2026-03-08 update sensor enclosure
    [Sensor enclosure.3dm, sensor-enclosure-base.stl, sensor-enclosure-top.stl]
